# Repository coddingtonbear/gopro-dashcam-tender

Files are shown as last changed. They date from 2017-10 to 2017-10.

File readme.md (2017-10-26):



I use my GoPro as a dashcam, and although I rarely need to take any footage
off of my device, the GoPro will slowly accumulate videos over time.  This
device provides an easy way for me to clear the GoPro at the end of the 
day by just plugging my GoPro into it as its charger.

## Components Required

In order of decreasing expense:

* 1x ESP-12F: These can be obtained for roughly $2 on AliExpress.  Other similar packages of the ESP8266 wifi module, or _maybe_ even the ESP-01 module should work with minimal modifications to the layout and schematic.
* 1x CH340G: ~$0.50 on AliExpress.
* 1x SOT-223 3.3V Voltage Regulator
* 2x SOT-23 NPN Transistors for the UART->ESP8266 reset circuit.  Note that there are alternative reset circuits.  See below for details.
* 1x HC-49 12MHz crystal
* Miscellaneous passives.

See the schematic's netlist for more details.

## Procedure

Essentially, what this device does is:

* Wait for a GoPro to be plugged-in to the USB-A port.  This can be detected because of the way connected USB devices pull up the D+/D- lines to indicate their operating speed.
* Connect to my home WIFI network to get an up-to-date UTC time using NTP.  Immediately disconnecting from my home WIFI network.
* Connect to the GoPro WIFI network, then:
  * Set the GoPro's time.
  * Clear all stored media.
  * Turn off the GoPro.

## Schematic



## Errata

You'll notice two differences between the above schematic and the photo of the board above:

* I had originally intended to control the power supply to the attached GoPro using a mosfet (you'll see a jumper lead in the above photo between two of three leads nearby the USB-A connector.  It should've been clearer earlier, but I won't be able to detect the GoPro being plugged-in unless I'm supplying 5V; because the GoPro won't pull on the D+/D- lines until it is being supplied with voltage.
* I never populated the RGB LED in the bottom-left area of the board.  The footprint I've used in the above photo is essentially impossible to use on a milled board given the positioning of the pins on the SLV6A LED.  I've corrected the footprint in the attached project.
* You won't be able to tell in the above photo, but I had originally neglected to add a pulldown on GPIO15.  This caused the device to boot up into the wrong mode.  This bug took me a ton of time to find, and I only discovered what was wrong by connecting a logic analyzer to the ESP-12F's TX pin in autobaud mode to notice that the device was communicating its boot state after resetting.

## Future

* I'd probably not bother with the transitor-based reeset circuit.  The circuit in use here was copied from the NodeMCU schematic, and, although fairly simple, isn't really necessary given that PlatformIO's ESP8266 tooling supports using the DTR and RTS pins for directly controlling Reset and GPIO0 directly.

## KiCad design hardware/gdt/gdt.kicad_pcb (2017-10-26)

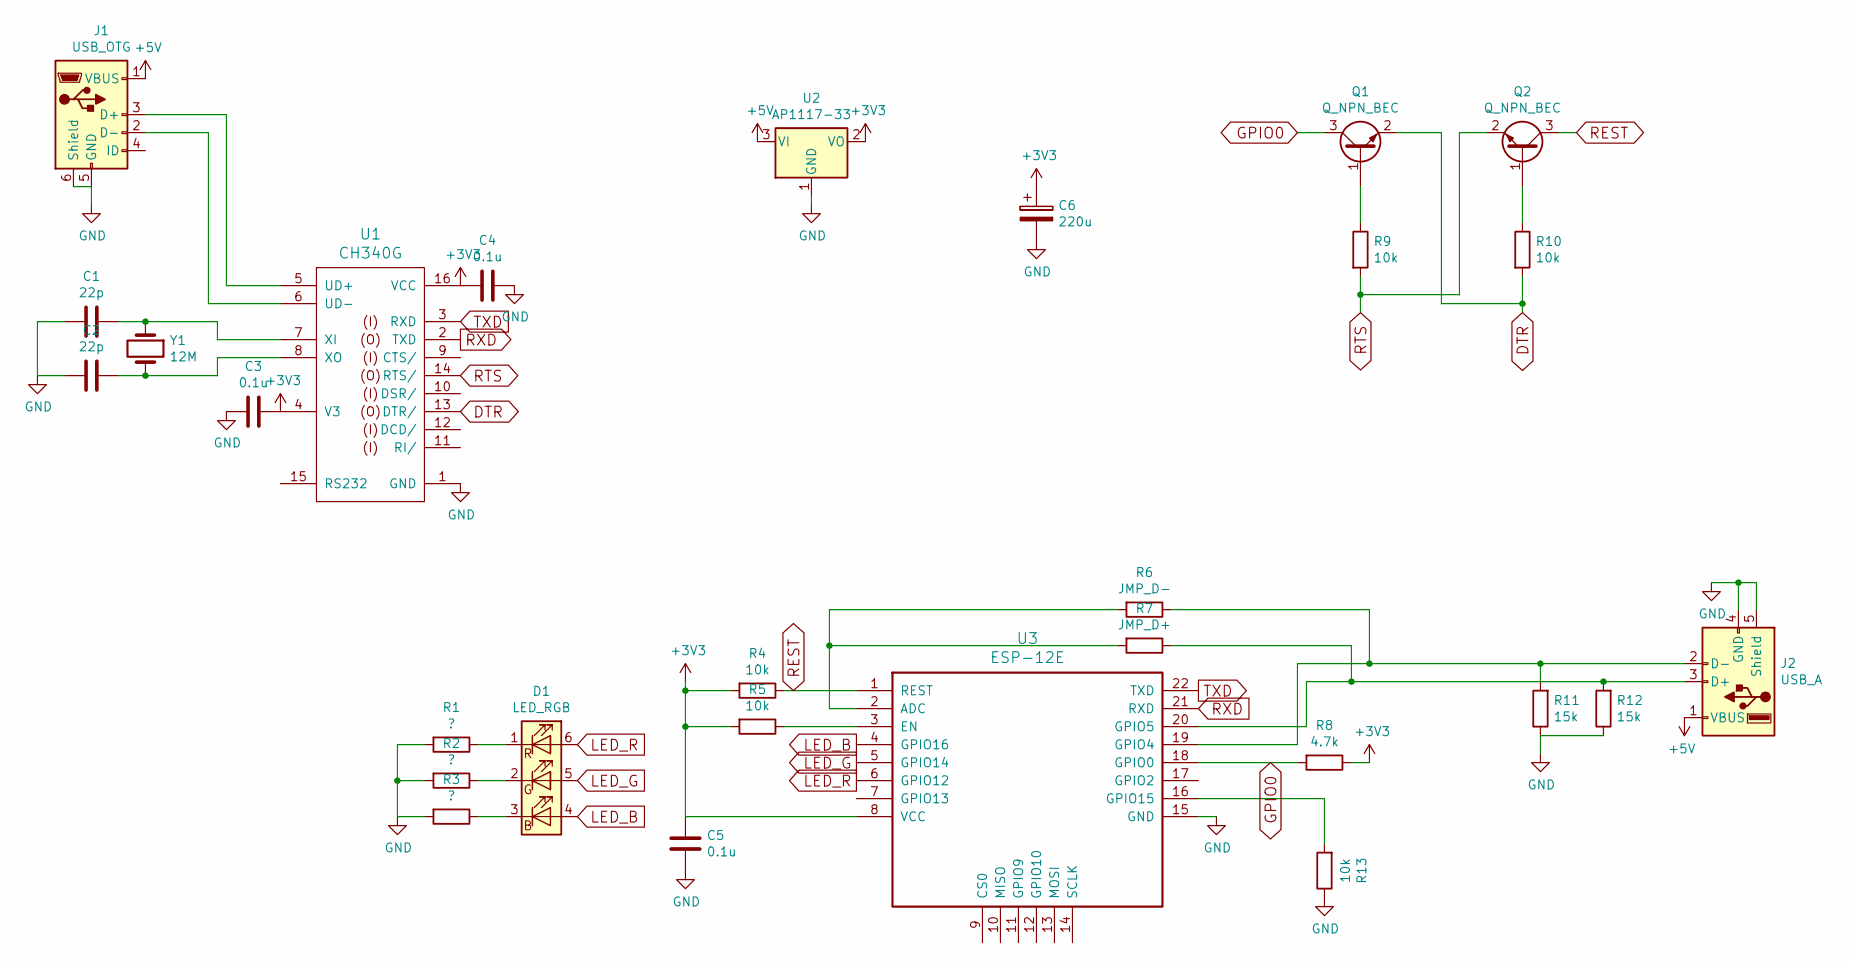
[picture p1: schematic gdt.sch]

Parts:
C1, C2: 22p; 0805_Milling
C3, C4, C5: 0.1u; 0805_Milling
C6: 220u; Capacitor_Electrolytic_D6.3xP2.5
D1: LED_RGB; SLV6A-FKB
J1: USB_OTG; UJ2-MIBH-4-SMT
J2: USB_A; USB_A_Female
Q1, Q2: Q_NPN_BEC; SOT-23_Handsoldering
R1, R2, R3: ?; 0805_Milling
R4, R5, R9, R10, R13: 10k; 0805_Milling
R6: JMP_D-; 0805_Milling
R7: JMP_D+; 0805_Milling
R8: 4.7k; 0805_Milling
R11, R12: 15k; 0805_Milling
U1: CH340G; SOIC-16
U2: AP1117-33; SOT223
U3: ESP-12E; ESP12E
Y1: 12M; XTAL-HC49US

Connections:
+3V3: C3.1, C4.2, C5.1, C6.1, R4.2, R5.2, R8.1, U1.4 (V3), U1.16 (VCC), U2.2 (VO), U3.8 (VCC)
+5V: J1.1 (VBUS), J2.1 (VBUS), U2.3 (VI)
DTR: Q1.2 (E), R10.2, U1.13 (DTR/)
GND: C1.2, C2.2, C3.2, C4.1, C5.2, C6.2, J1.5 (GND), J1.6 (Shield), J2.4 (GND), J2.5 (Shield), R1.2, R2.2, R3.2, R11.1, R12.1, R13.1, U1.1 (GND), U2.1 (GND), U3.15 (GND)
GPIO0: Q1.3 (C), R8.2, U3.18 (GPIO0)
LED_B: D1.4 (BA), U3.4 (GPIO16)
LED_G: D1.5 (GA), U3.5 (GPIO14)
LED_R: D1.6 (RA), U3.6 (GPIO12)
unnamed: C1.1, U1.7 (XI), Y1.1
unnamed: C2.1, U1.8 (XO), Y1.2
unnamed: D1.1 (RK), R1.1
unnamed: D1.2 (GK), R2.1
unnamed: D1.3 (BK), R3.1
unnamed: J1.2 (D-), U1.6 (UD-)
unnamed: J1.3 (D+), U1.5 (UD+)
unnamed: J2.2 (D-), R6.1, R11.2, U3.19 (GPIO4)
unnamed: J2.3 (D+), R7.1, R12.2, U3.20 (GPIO5)
unnamed: Q1.1 (B), R9.1
unnamed: Q2.1 (B), R10.1
unnamed: R5.1, U3.3 (EN)
unnamed: R6.2, R7.2, U3.2 (ADC)
unnamed: R13.2, U3.16 (GPIO15)
REST: Q2.3 (C), R4.1, U3.1 (REST)
RTS: Q2.2 (E), R9.2, U1.14 (RTS/)
RXD: U1.2 (TXD), U3.21 (RXD)
TXD: U1.3 (RXD), U3.22 (TXD)

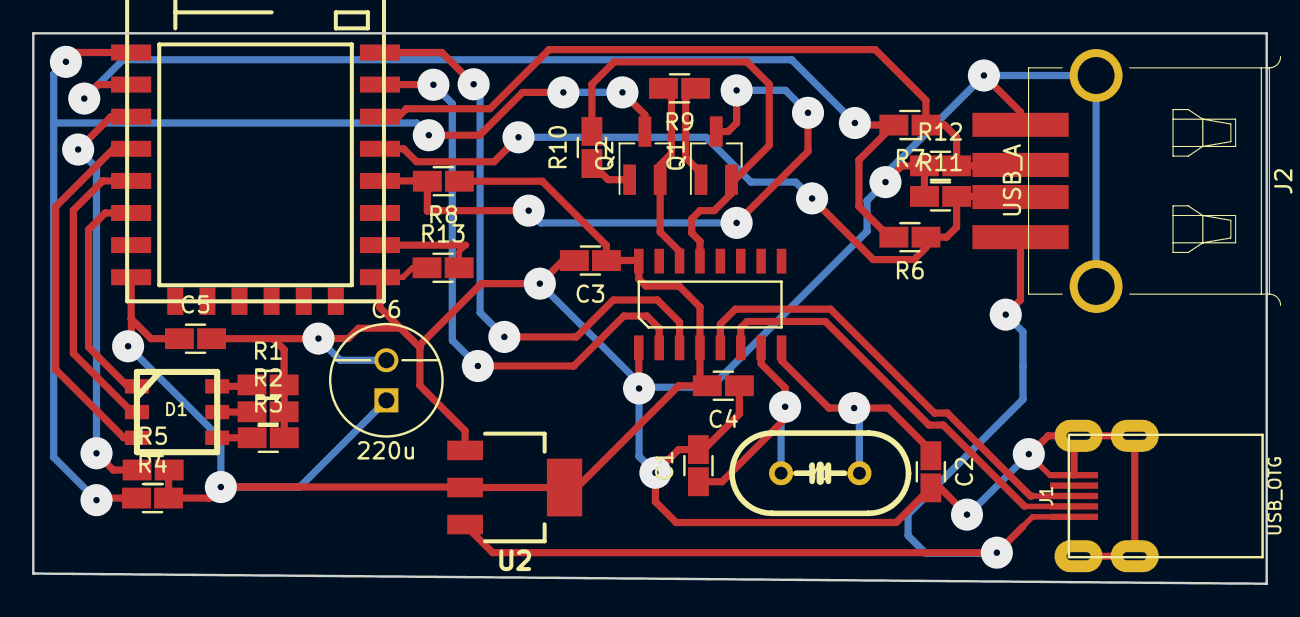
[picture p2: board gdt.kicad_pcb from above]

Board: 2 copper layers, 76.8 x 34.3 mm, 28 parts (0 on the bottom side), 26 nets.

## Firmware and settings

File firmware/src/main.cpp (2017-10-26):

#include "main.h"

WiFiUDP Udp;
unsigned int localNtpPort = 8888;
byte ntpPacketBuffer[NTP_PACKET_SIZE];

int beganSearch = 0;
bool connected = false;

void setup() {
    Serial.begin(115200);
    WiFi.mode(WIFI_STA);

    pinMode(DPLUS_DETECT_PIN, INPUT);
    pinMode(DMINUS_DETECT_PIN, INPUT);
    pinMode(CHARGE_CONTROL_PIN, OUTPUT);
    digitalWrite(CHARGE_CONTROL_PIN, HIGH);

    setNtpTime();
}

void loop() {
    uint8_t d_plus = digitalRead(DPLUS_DETECT_PIN);
    uint8_t d_minus = digitalRead(DMINUS_DETECT_PIN);

    if(d_minus || d_plus) {
        if(!connected) {
            connected = true;
            printTime();
            Serial.println(": Gopro connected.");
            tendGopro();
        }
    } else {
        connected = false;
    }

    delay(1000);
}

void printTime() {
    time_t t = now();
    Serial.print(year(t));
    Serial.print("-");
    Serial.print(month(t));
    Serial.print("-");
    Serial.print(day(t));
    Serial.print("T");
    Serial.print(hour(t));
    Serial.print(":");
    Serial.print(minute(t));
    Serial.print(":");
    Serial.print(second(t));
    Serial.print(" UTC");
    Serial.print(TIME_ZONE);
}

void tendGopro() {
    // Make sure time is up-to-date
    setNtpTime();

    // Now let's set up the gopro
    WiFi.begin(GOPRO_WIFI_SSID, GOPRO_WIFI_PWD);
    Serial.print("Connecting to GoPro WiFi network '");
    Serial.print(GOPRO_WIFI_SSID);
    Serial.println("'...");

    int started = millis();
    while(WiFi.status() != WL_CONNECTED) {
        delay(500);
        Serial.print('.');
        if(millis() > started + WIFI_TIMEOUT) {
            Serial.println("");
            WiFi.disconnect();
            Serial.println("Connection failed.");
            return;
        }
    }
    Serial.println("");
    Serial.print("Connected as ");
    Serial.println(WiFi.localIP());

    RestClient client = RestClient(GOPRO_IP, 80);
    client.setReadTimeout(1000);

    time_t t = now();
    String url; 
    int status = 0;

    Serial.println("Setting time...");
    char timeBytes[18];
    sprintf(
        timeBytes,
        "%%%02X%%%02X%%%02X%%%02X%%%02X%%%02X",
        year(t) - 2000,
        month(t),
        day(t),
        hour(t),
        minute(t),
        second(t)
    );
    String timeString = String(timeBytes);
    timeString.toLowerCase();
    url = String(
        "/camera/TM?t="
        + String(GOPRO_WIFI_PWD)
        + "&p="
        + timeString
    );
    sendGoProRequest(client, url);

    Serial.println("Deleting files...");
    url = String(
        "/camera/DA?t="
        + String(GOPRO_WIFI_PWD)
    );
    sendGoProRequest(client, url);
    
    Serial.println("Turning camera off...");
    url = String(
        "/bacpac/PW?t="
        + String(GOPRO_WIFI_PWD)
        + "&p=%00"
    );
    sendGoProRequest(client, url);

    WiFi.disconnect();
    Serial.println("Disconnected from GoPro WiFi network.");
}

int sendGoProRequest(RestClient& client, String& url) {
    char urlBuffer[250];
    int statusCode = 0;

    url.toCharArray(urlBuffer, 250);

    statusCode = client.get(urlBuffer);

    Serial.print("Result: HTTP ");
    Serial.println(statusCode);

    return statusCode;
}

void setNtpTime() {
    WiFi.begin(HOME_WIFI_SSID, HOME_WIFI_PWD);

    Serial.print("Connecting to home WiFi network '");
    Serial.print(HOME_WIFI_SSID);
    Serial.println("'...");
    while(WiFi.status() != WL_CONNECTED) {
        delay(500);
        Serial.print('.');
    }
    Serial.println();
    Serial.print("Connected as ");
    Serial.println(WiFi.localIP());

    Serial.print("Starting UDP on port ");
    Udp.begin(localNtpPort);
    Serial.print(Udp.localPort());
    Serial.println("...");

    time_t currentTime = getNtpTime();
    if(currentTime) {
        setTime(currentTime);
    }

    WiFi.disconnect();
    Serial.println("Disconnected from home WiFi network.");

    Serial.print("Current time: ");
    printTime();
    Serial.println();
}

time_t getNtpTime() {
    // See: https://github.com/PaulStoffregen
    //   /Time/blob/master/examples/TimeNTP_ESP8266WiFi/TimeNTP_ESP8266WiFi.ino
    // for details
    IPAddress ntpServerIP;

    while(Udp.parsePacket() > 0);  // Drop existing packets

    Serial.println("Sending NTP request...");
    WiFi.hostByName(NTP_SERVER_NAME, ntpServerIP);
    Serial.print(NTP_SERVER_NAME);
    Serial.print(':');
    Serial.println(ntpServerIP);

    sendNtpPacket(ntpServerIP);
    uint32_t beginWait = millis();
    while(millis() - beginWait < 1500) {
        int size = Udp.parsePacket();
        if(size >= NTP_PACKET_SIZE) {
            Serial.println("NTP Response received.");
            Udp.read(ntpPacketBuffer, NTP_PACKET_SIZE);

            unsigned long secsSince1900;
            // convert four bytes starting at location 40 to a long integer
            secsSince1900 =  (unsigned long)ntpPacketBuffer[40] << 24;
            secsSince1900 |= (unsigned long)ntpPacketBuffer[41] << 16;
            secsSince1900 |= (unsigned long)ntpPacketBuffer[42] << 8;
            secsSince1900 |= (unsigned long)ntpPacketBuffer[43];
            return secsSince1900 - 2208988800UL + TIME_ZONE * SECS_PER_HOUR;
        }
    }
    Serial.println("No response received from NTP.");
    return 0;
}

void sendNtpPacket(IPAddress &address) {
    // See: https://github.com/PaulStoffregen
    //   /Time/blob/master/examples/TimeNTP_ESP8266WiFi/TimeNTP_ESP8266WiFi.ino
    // for details

    // set all bytes in the buffer to 0
    memset(ntpPacketBuffer, 0, NTP_PACKET_SIZE);
    // Initialize values needed to form NTP request
    // (see URL above for details on the packets)
    ntpPacketBuffer[0] = 0b11100011;   // LI, Version, Mode
    ntpPacketBuffer[1] = 0;     // Stratum, or type of clock
    ntpPacketBuffer[2] = 6;     // Polling Interval
    ntpPacketBuffer[3] = 0xEC;  // Peer Clock Precision
    // 8 bytes of zero for Root Delay & Root Dispersion
    ntpPacketBuffer[12] = 49;
    ntpPacketBuffer[13] = 0x4E;
    ntpPacketBuffer[14] = 49;
    ntpPacketBuffer[15] = 52;
    // all NTP fields have been given values, now
    // you can send a packet requesting a timestamp:
    Udp.beginPacket(address, 123); //NTP requests are to port 123
    Udp.write(ntpPacketBuffer, NTP_PACKET_SIZE);
    Udp.endPacket();
}

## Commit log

2017-10-17 And so it begins...
    [gdt.kicad_pcb, gdt.sch]
2017-10-20 Whoops; this put it into boot mode 5 during reset rather than 1 -- forgot a pulldown resistor.
    [gdt.kicad_pcb, gdt.sch]
2017-10-26 Uploading final version of hardware/software.
    [gdt.kicad_pcb, gdt.sch]
2017-10-26 Update readme.md
    Whoops; those aren't mosfets.
